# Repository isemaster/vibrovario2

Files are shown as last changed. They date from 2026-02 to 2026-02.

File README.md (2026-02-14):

# VibroVario2 - Watchy V3 with BMP390 Integration

## Overview
This is a modified version of the Watchy V3.0 board with integrated BMP390 barometric pressure sensor for variometer applications.

## Changes from Original Watchy V3.0

### Added Components
1. **BMP390** (U5) - Barometric Pressure Sensor
   - Package: LGA-10 (2.0x2.0x0.75mm)
   - I2C Address: 0x77 (SDO tied to GND)
   - Position: Near ESP32-S3

2. **Decoupling Capacitors** (per BMP390 datasheet)
   - C22: 100nF (0402) - High-frequency decoupling
   - C23: 1uF (0402) - Bulk decoupling

### Pin Connections
| BMP390 Pin | Function | ESP32-S3 GPIO | Net Name |
|---|---|---|---|
| 1 | GND | - | GND |
| 2 | VDDIO | - | +3V3 |
| 3 | SDO | - | GND (sets I2C addr 0x77) |
| 4 | INT2 | - | NC |
| 5 | VDD | GPIO45 | BMP390_PWR |
| 6 | INT1 | - | NC |
| 7 | SCL | GPIO11 | SCL |
| 8 | SDA | GPIO12 | SDA |
| 9 | CSB | - | +3V3 (I2C mode) |
| 10 | GND | - | GND |

### Power Control
- BMP390 VDD is connected to GPIO45 for power management
- Set GPIO45 HIGH to enable BMP390
- Set GPIO45 LOW to disable BMP390 (power saving mode)

## Files Structure
```
vibrovario2/
├── vibrovario2.kicad_sch    # Schematic with BMP390
├── vibrovario2.kicad_pcb    # PCB with BMP390 placed
├── vibrovario2.kicad_pro    # Project file
├── BMP390.kicad_sym         # BMP390 symbol library
├── vibrovario2.lib          # Legacy symbol library
├── sym-lib-table            # Symbol library table
├── vibrovario2.pretty/      # Footprint library
│   └── BMP390_LGA-10.kicad_mod
└── README.md
```

## Assembly Notes
1. BMP390 is a small LGA-10 package (2x2mm) - requires precise soldering
2. Recommend using solder paste and hot air reflow for BMP390
3. Decoupling capacitors should be placed close to BMP390 VDD pin
4. All components are SMD for factory assembly

## Firmware Integration
For Arduino/PlatformIO:

```cpp
#include <Wire.h>
#include <Adafruit_BMP3XX.h>

#define BMP390_SDA 12
#define BMP390_SCL 11
#define BMP390_PWR 45

Adafruit_BMP3XX bmp;

void setup() {
  // Enable BMP390 power
  pinMode(BMP390_PWR, OUTPUT);
  digitalWrite(BMP390_PWR, HIGH);
  delay(10);  // Wait for power stabilization

  // Initialize I2C
  Wire.begin(BMP390_SDA, BMP390_SCL);

  // Initialize BMP390
  if (!bmp.begin_I2C(0x77)) {
    Serial.println("BMP390 not found!");
    while (1);
  }

  // Configure for variometer use
  bmp.setTemperatureOversampling(BMP3_OVERSAMPLING_8X);
  bmp.setPressureOversampling(BMP3_OVERSAMPLING_4X);
  bmp.setIIRFilterCoeff(BMP3_IIR_FILTER_COEFF_3);
  bmp.setOutputDataRate(BMP3_ODR_25_HZ);
}

void loop() {
  if (bmp.performReading()) {
    float altitude = bmp.readAltitude(1013.25);
    Serial.printf("Altitude: %.2f m\n", altitude);
  }
  delay(100);
}
```

## BOM Additions
| Reference | Value | Package | Manufacturer | MPN | LCSC |
|---|---|---|---|-----|---|
| U5 | BMP390 | LGA-10 | Bosch | BMP390 | C496091 |
| C22 | 100nF | 0402 | Samsung | CL05B104JB5NNNC | C1525 |
| C23 | 1uF | 0402 | Samsung | CL05A105KA5NQNC | C52923 |

## License
Based on Watchy by SQFMI (https://sqfmi.com/watchy)
Original hardware design: MIT License

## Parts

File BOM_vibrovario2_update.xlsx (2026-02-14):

VibroVario2 Bill of Materials
Reference | Description | Value | Package | Manufacturer | MPN | LCSC | Qty
U5 | Barometric Pressure Sensor | BMP390 | LGA-10 2x2mm | Bosch Sensortec | BMP390 | C496091 | 1
C22 | Decoupling Capacitor | 100nF | 0402 | Samsung | CL05B104JB5NNNC | C1525 | 1
C23 | Decoupling Capacitor | 1uF | 0402 | Samsung | CL05A105KA5NQNC | C52923 | 1

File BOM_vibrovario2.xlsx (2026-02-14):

Bill of Materials - Watchy V3 с интегрированным BMP390
Вариометр VibroVario на базе Watchy V3.0 ESP32-S3
# | Designator | Description | Value | Package | Qty | Manufacturer | MPN | Source | Notes
1 | U4 | Microcontroller ESP32-S3FN8 | ESP32-S3FN8 | QFN-56 | 1 | Espressif | ESP32-S3FN8 | LCSC/Mouser | Main MCU
2 | U3 | Battery Charger | TP4054 | SOT-23-5 | 1 | NanJing TopPower | TP4054 | LCSC | LiPo charger
3 | U1 | LDO Voltage Regulator | ME6211C33M5G-N | SOT-23-5 | 1 | Microne | ME6211C33M5G-N | LCSC | 3.3V LDO
4 | U2 | Real Time Clock | PCF8563 | SOIC-8 | 1 | NXP | PCF8563BS | LCSC/Mouser | RTC
5 | U5 | 3-Axis Accelerometer | BMA423 | LGA-12 | 1 | Bosch | BMA423 | LCSC | Motion sensor
6 | U6 | Barometric Pressure Sensor | BMP390 | LGA-10 2x2mm | 1 | Bosch | BMP390 | LCSC/Mouser | NEW! Vario sensor
7 | J3 | E-Ink Display Connector | FPC 24-pin 0.5mm | ZIF | 1 | JUSHUO | AFC07-S24ECC-00 | LCSC | Display FPC
8 | DS1 | E-Ink Display 1.54" | GDEY0154D67 | 200x200 | 1 | Good Display | GDEY0154D67 | Good Display | Not included in PCBA
9 | C1, C2 | Capacitor Ceramic | 10µF 6.3V | 0402 | 2 | Murata/TF | GRM155R60J106ME15D | LCSC
10 | C3, C4, C5 | Capacitor Ceramic | 100nF 6.3V | 0402 | 3 | Murata/TF | GRM155R60J104ME15D | LCSC | Decoupling
11 | C6 | Capacitor Ceramic | 1µF 6.3V | 0402 | 1 | Murata/TF | GRM155R60J105ME15D | LCSC | BMP390 VDD filter
12 | C7 | Capacitor Ceramic | 100nF 6.3V | 0402 | 1 | Murata/TF | GRM155R60J104ME15D | LCSC | NEW! BMP390 decoupling
13 | C8 | Capacitor Ceramic | 1µF 6.3V | 0402 | 1 | Murata/TF | GRM155R60J105ME15D | LCSC | NEW! BMP390 VDDIO
14 | C20, C21 | Capacitor Ceramic | 4.7µF 50V | 0603 | 2 | Murata/TF | GRM188R61H475KE15D | LCSC | Display circuit
15 | R1, R2 | Resistor | 10kΩ | 0402 | 2 | Yageo/TF | RC0402FR-0710KL | LCSC | I2C pullup (SDA/SCL)
16 | R3 | Resistor | 4.7kΩ | 0402 | 1 | Yageo/TF | RC0402FR-074K7L | LCSC | BMP390 CSB pullup
17 | R4, R5, R6, R7 | Resistor | 100kΩ | 0402 | 4 | Yageo/TF | RC0402FR-07100KL | LCSC | Button pullup
18 | R8 | Resistor | 2.2Ω | 0402 | 1 | Yageo/TF | RC0402FR-072R2L | LCSC | Display
19 | R9 | Resistor | 1MΩ | 0402 | 1 | Yageo/TF | RC0402FR-071ML | LCSC | Display
20 | D1 | LED Blue | Blue LED | 0603 | 1 | Everlight | 19-217/BHC-ZL1V2QY/3T | LCSC | Status LED
21 | D2 | LED Red | Red LED | 0603 | 1 | Everlight | 19-217/R6C-AL2M2VY/3T | LCSC | Charge LED
22 | D3, D4, D5 | Schottky Diode | MBR0530 | SOD-123 | 3 | Onsemi | MBR0530T1G | LCSC | Display circuit
23 | Q1 | PMOS Transistor | AO3401A | SOT-23 | 1 | AOS | AO3401A | LCSC | Power switch
24 | Q2 | NPN Transistor | S8050 | SOT-23 | 1 | CJ | S8050 | LCSC | LED driver
25 | Q3 | NMOS Transistor | AO3400A | SOT-23 | 1 | AOS | AO3400A | LCSC | Display circuit
26 | L1 | Inductor | 10µH 0.3A | 0603 | 1 | Murata | LQM18FN100N00D | LCSC | Display circuit
27 | L2 | Inductor | 47µH 0.5A | NR-40xx | 1 | Taiyo Yuden | NR4018T470M | LCSC | Display circuit
28 | J1 | Battery Connector | JST 1.25mm 2-pin | SMD | 1 | JST | S2B-PH-SM4 | LCSC | LiPo battery
29 | J2 | USB Micro-B | USB Micro-B | SMD | 1 | Korean Hroparts | U-F-M5DD-Y-L | LCSC | USB charging
30 | J4 | Vibration Motor Header | 2-pin 1.25mm | SMD | 1 | JST | S2B-PH-SM4 | LCSC | Vibro motor
31 | SW1, SW2, SW3, SW4 | Tactile Switch | SPST | SMD 4.5x4.5mm | 4 | Korean Hroparts | K2-1114SA-A4SW-06 | LCSC | Menu/Back/Up/Down
32 | Y1 | Crystal 32.768kHz | 32.768kHz | FC-135 3.2x1.5mm | 1 | Epson | FC-135 32.7680KA-AG0 | LCSC | RTC crystal
33 | Y2 | Crystal 40MHz | 40MHz | 4-pin 2.5x2.0mm | 1 | Abracon | ABS07-40.000MHZ-4-T | LCSC | ESP32 crystal
34 | AE1 | PCB Antenna | 2.4GHz | PCB | 1 | - | SWRA117D | On PCB | WiFi/BT antenna
35 | BAT1 | LiPo Battery | 200mAh 3.7V | 402030 | 1 | - | GM042030 | AliExpress | Not included in PCBA
36 | M1 | Vibration Motor | 1020 | 10mm | 1 | - | 1020 | LCSC | Not included in PCBA
ИТОГО: |  |  |  |  | 36
ПРИМЕЧАНИЯ:
• Зеленым выделены НОВЫЕ компоненты для интеграции BMP390
• BMP390 I2C адрес: 0x77 (SDO подтянут к VDDIO)
• Питание BMP390: GPIO45 (управляемое включение)
• I2C: SDA=GPIO12, SCL=GPIO11 (общая шина с BMA423 и PCF8563)
• Футпринт BMP390: LGA-10, 2.0×2.0×0.75mm (металлическая крышка)

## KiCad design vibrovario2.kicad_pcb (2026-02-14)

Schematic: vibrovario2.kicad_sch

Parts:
AE1: Antenna_Chip; SWRA117D
C1, C10: 10uF; C_0402_1005Metric
C2, C3, C4, C15: 1uF; C_0402_1005Metric
C5, C6, C11, C12, C13, C14: 100nF; C_0402_1005Metric
C7, C9: 3pF; C_0402_1005Metric
C16, C19: 26pF; C_0402_1005Metric
C17, C18: 10pF; C_0402_1005Metric
C20, C21: 4.7uF/50V; C_0603_1608Metric
C22, C23, C24, C25, C26, C27, C28, C29: 1uF/50V; C_0402_1005Metric
D1, D3, D4, D5: MBR0530; D_SOD-123
D2: 1N4001; D_SOD-123F
J1: Battery; 1.25T-2PWT (Molex 532610271)
J2: Micro USB; USB_Micro-B
J3: FPC24(0.5MM); 24_Pins_0.5mm_Pitch_ZIF_Connector_UP
L1: 7.5nH; L_0402_1005Metric
L2: 47uH 0.5A; L_Taiyo-Yuden_NR-40xx
M1: Vibration_Motor; Motor_Header
Q1: CJ2301; SOT-23
Q2: S8050; SOT-23
Q3: AO3400A; SOT-23
R1, R3, R18, R20: 10K; R_0402_1005Metric
R2, R4, R6, R7, R8, R10, R11, R15, R19: 100K; R_0402_1005Metric
R5, R14: 51K; R_0402_1005Metric
R9: 360K; R_0402_1005Metric
R12, R16: 1M; R_0402_1005Metric
R13: 1K; R_0402_1005Metric
R17: 2.2; R_0402_1005Metric
SW1: BTN2; EVQPUC
SW2: BTN1; EVQPUC
SW3: BTN3; EVQPUC
SW4: BTN4; EVQPUC
TP1: TX; TestPoint_Pad_D1.0mm
TP2: RX; TestPoint_Pad_D1.0mm
TP3: BOOT; TestPoint_Pad_D1.0mm
TP4: 3V3; TestPoint_Pad_D1.0mm
TP5: GND; TestPoint_Pad_D1.0mm
TP6: SCL; TestPoint_Pad_D1.0mm
TP7: SDA; TestPoint_Pad_D1.0mm
U1: SR2HARU
U2: RT908033; SOT-23-5
U3: TP4054; SOT-23-5
U4: ESP32-S3; QFN-56-1EP_7x7mm_P0.4mm_EP5.6x5.6mm
U5: USBLC6-2P6; SOT-666
U6: BMA423; LGA-12_2x2mm_P0.5mm
Y1: 32.768KHz; Crystal_SMD_2012-2Pin_2.0x1.2mm
Y2: 40MHz; Crystal_SMD_2520-4Pin_2.5x2.0mm

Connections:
+3V3: C1.1, C3.1, C4.1, C5.1, C6.1, C10.1, C14.1, C20.1, C28.1, D2.1 (K), J3.15, J3.16, L2.2, M1.1 (+), R1.2, R4.2, R7.2, R10.2, R11.2, R18.2, R19.1, R20.2, TP4.1, U1.6 (VCC), U2.5 (VOUT), U4.2 (VDD3P3), U4.3 (VDD3P3), U4.20 (VDD3P3_RTC), U4.46 (VDD3P3_CPU), U4.55 (VDDA), U4.56 (VDDA), U6.3 (VDDIO), U6.7 (VDD), U6.10 (CSB); also elsewhere on the board
+BATT: J1.1, Q1.3 (D), R8.1, U3.3 (VBAT)
/32K_N: C18.1, U4.22 (GPIO16/ADC2_CH5/XTAL_32K_N), Y1.2
/32K_P: C17.1, U4.21 (GPIO15/ADC2_CH4/XTAL_32K_P), Y1.1
/40M_P: C16.1, R12.2, Y2.1
ACC_INT_1: U4.19 (GPIO14/ADC2_CH3), U6.5 (INT1)
ACC_INT_2: U4.18 (GPIO13/ADC2_CH2), U6.6 (INT2)
ADC: C11.1, R8.2, R9.1, U4.14 (GPIO9/ADC1_CH8)
BMP390_PWR: U4.51 (GPIO45); also elsewhere on the board
BTN1: R4.1, SW2.1 (A), U4.12 (GPIO7/ADC1_CH6)
BTN2: R7.1, SW1.1 (A), U1.2 (~SR1), U4.11 (GPIO6/ADC1_CH5)
BTN3: R10.1, SW3.1 (A), TP3.1, U1.5 (~SR0), U4.5 (GPIO0/BOOT)
BTN4: R11.1, SW4.1 (A), U4.13 (GPIO8/ADC1_CH7)
BUSY: J3.9, U4.41 (GPIO36)
CS: J3.12, U4.38 (GPIO33)
DC: J3.11, U4.39 (GPIO34)
DN: J2.2 (D-), U5.4 (I/O2)
DP: J2.3 (D+), U5.6 (I/O1)
EN: C2.1, R1.1, U1.3 (~RST), U4.4 (CHIP_PU/RESET)
GDR: J3.2, Q3.1 (G), R16.1
MOSI: J3.14, U4.36 (SPICLK_N/GPIO48)
unnamed: AE1.1 (FEED), C7.1, L1.1
unnamed: D1.1 (K), Q1.2 (S), U2.1 (VIN), U2.3 (EN)
unnamed: C14.2, D2.2 (A), M1.2 (-), Q2.3 (C)
unnamed: C21.1, D3.1 (K), D4.2 (A)
unnamed: C21.2, D5.2 (A), L2.1, Q3.3 (D)
unnamed: C23.1, J3.5
unnamed: C24.1, J3.18
unnamed: C25.1, J3.20
unnamed: C26.1, J3.22
unnamed: C27.1, J3.24
unnamed: Q2.1 (B), R13.1
unnamed: R3.2, U3.5 (PROG)
unnamed: R6.2, U3.1 (STAT)
unnamed: C9.1, L1.2, U4.1 (LNA_IN/RF)
unnamed: TP2.1, U4.50 (U0RXD/PROG/GPIO44)
unnamed: TP1.1, U4.49 (U0TXD/PROG/GPIO43)
unnamed: R12.1, U4.54 (XTAL_P)
PREVGH: C22.1, D5.1 (K), J3.21
PREVGL: C29.2, D3.2 (A), J3.23
RES: J3.10, R19.2, U4.40 (GPIO35)
RESE: J3.3, Q3.2 (S), R17.2
SCK: J3.13, U4.37 (SPICLK_P/GPIO47)
SCL: R20.1, TP6.1, U4.16 (GPIO11/ADC2_CH0), U6.12 (SCX); also elsewhere on the board
SDA: R18.1, TP7.1, U4.17 (GPIO12/ADC2_CH1), U6.2 (SDX); also elsewhere on the board
STAT: R5.2, R6.1, U4.15 (GPIO10/ADC1_CH9)
USB_D+: U4.26 (GPIO20/USB_D+/ADC2_CH9), U5.1 (I/O1)
USB_D-: U4.25 (GPIO19/USB_D-/ADC2_CH8), U5.3 (I/O2)
USB_DET: R14.2, R15.1, U4.27 (GPIO21)
VBUS: C12.1, D1.2 (A), J2.1 (VBUS), Q1.1 (G), R2.1, R5.1, R14.1, U3.4 (VDD), U5.5 (VBUS)
VDD: C13.1, C15.1, U4.29 (VDD_SPI)
VIB_PWM: R13.2, U4.23 (GPIO17/ADC2_CH6/DAC_2)

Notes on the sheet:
Vibration Motor
Buttons
E-Paper Driver
Accelerometer
ESP32-S3
USB
Power & Battery

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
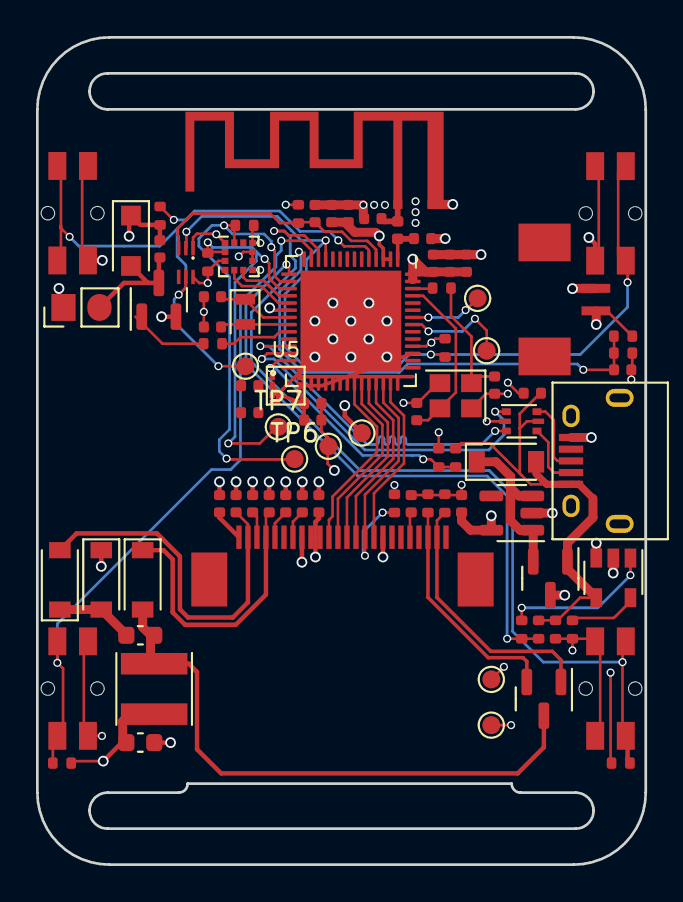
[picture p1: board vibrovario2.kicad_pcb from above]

Board: 4 copper layers, 33.8 x 46.0 mm, 87 parts (0 on the bottom side), 54 nets.

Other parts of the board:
C22#2: 100nF; C_0402_1005Metric
C23#2: 1uF; C_0402_1005Metric
TP4#2: 3V3; TestPoint_Pad_D1.0mm
TP5#2: GND; TestPoint_Pad_D1.0mm
U5#2: BMP390; BMP390_LGA-10

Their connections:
+3V3: TP4#2.1, U5#2.2 (VDDIO), U5#2.9 (CSB); also elsewhere on the board
BMP390_PWR: C22#2.1, C23#2.1, U5#2.5 (VDD); also elsewhere on the board
SCL: U5#2.7 (SCL); also elsewhere on the board
SDA: U5#2.8 (SDA); also elsewhere on the board
